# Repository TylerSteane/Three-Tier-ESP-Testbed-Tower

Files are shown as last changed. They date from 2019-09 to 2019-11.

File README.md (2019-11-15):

# Three Tier ESP Testbed Tower

Various research activities require the programming of a large numbers of devices.  This programming can be difficult to co-ordinate and organise, and requires considerable labour time. These issues often mean that testing on real hardware is abandoned or taken only to small scale implementation thus limiting the real-world findings. The method described in the paper 'A Three Tier Rapid Mass Programming Method', adopts a three tiered approach to programming large numbers of devices. Tier 1 is comprised of a single Master Controller which is networked to individual tower modules, these towers form the final 2 tiers with the Local Controller as tier 2 and up-to 15 target devices forming tier 3. The Master Controller co-ordinates and distributes the code for each device to the Local Controller which then programs the target devices. In the domain of networking this allows for:

	* Large networks of varied protocols to be programmed quickly, since towers are programmed in parallel, additional towers don't extend programming times.
	
	* Distributed networks are possible since towers are controlled over Ethernet.
	
	* Low cost as each tower costs around  ~$110 USD.
	
	* Dramatically reduced labour time and defect rates due to human error in setting up devices.

This project implements this method for IoT Networking research with ESP-01 Target devices, including both hardware and software implementations.
Please see the Wiki for instructions on [Configuring a Tower](https://bitbucket.org/tylersteane/three-tier-esp-testbed-tower/wiki/Configuring%20a%20Tower%20Controller)

# Acknowledgement

This work is presented in the research paper : [A Three Tier Rapid Mass Programming Method](https://doi.org/10.1016/j.mex.2019.10.003).
As originally proposed and envisioned by Tyler Steane, with technical work completed by Micheal Trifilo (software) & Christopher Rogash (hardware) as over seen by Tyler Steane & Dr. PJ Radcliffe.

# Citation
Please make use of this project in any of your own work (See [LICENSE](https://github.com/TylerSteane/Three-Tier-ESP-Testbed-Tower/blob/master/LICENSE)), If using any part of this work please cite as:

T. Steane, M. Trifilo, C. Rogash, and P. J. Radcliffe, “A three tier rapid mass programming method,” MethodsX, vol. 6, pp. 2396–2407, Jan. 2019.

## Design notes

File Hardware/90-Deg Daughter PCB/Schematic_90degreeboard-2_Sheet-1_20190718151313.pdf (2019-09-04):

A | A
B | B
C | C
D | D

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
### TITLE:

New Schematic | REV: 1.0
Date: | 2018-09-18 | Sheet: 1/1
EasyEDA V5.7.26 | Drawn By: s3544913

ESP01

U1

GND 1

2TXD 2

GPIO2 3

CHPD 4

VCC 5

RXD 6

RST 7

GPIO0 8

ESP01

U2

GND 1

2TXD 2

GPIO2 3

CHPD 4

VCC 5

RXD 6

RST 7

GPIO0 8

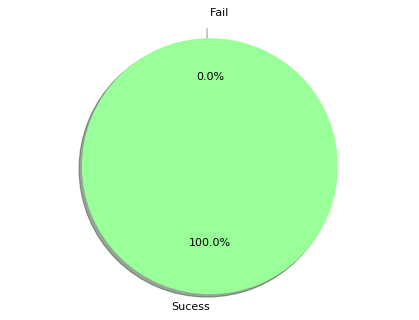
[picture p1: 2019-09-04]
Software/Mgmt_PC/pie.png

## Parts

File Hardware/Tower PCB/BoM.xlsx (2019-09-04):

1 Tower BOM
Part | Quantity | RS Stock Number
Multiplexer – SN74LV4051AN | 8 | 810-0142
Inverter - CD4069UBE | 1 | 527-596
Capacitor - 470µF | 15 | 520-1416
Capacitor – 47nF | 15 | 173-4794
Resistor – 10kΩ | 90 | 165-1031
Headers – 2x20 | 5 | 674-2365
Headers – 2x20 (Right Angle) | 4 | 468-1366
Switches | 15 | Not at RS, source from ali express here (https://www.aliexpress.com/item/20pcs-lot-Electrical-Toggle-Switches-Position-SPDT-1P2T-3-PIN-PCB-Panel-Assembly-Mini-Slide-Switch/32836683151.html)
5V power supply – LRS-100-5 | 1 | 106-5843
Raspberry Pi 3b+ | 1 | 137-3331
Terminal | 1 | 494-8956
Linear Regulator – LM1086CT-3.3/NOPB | 7 | 533-9448
TOTAL

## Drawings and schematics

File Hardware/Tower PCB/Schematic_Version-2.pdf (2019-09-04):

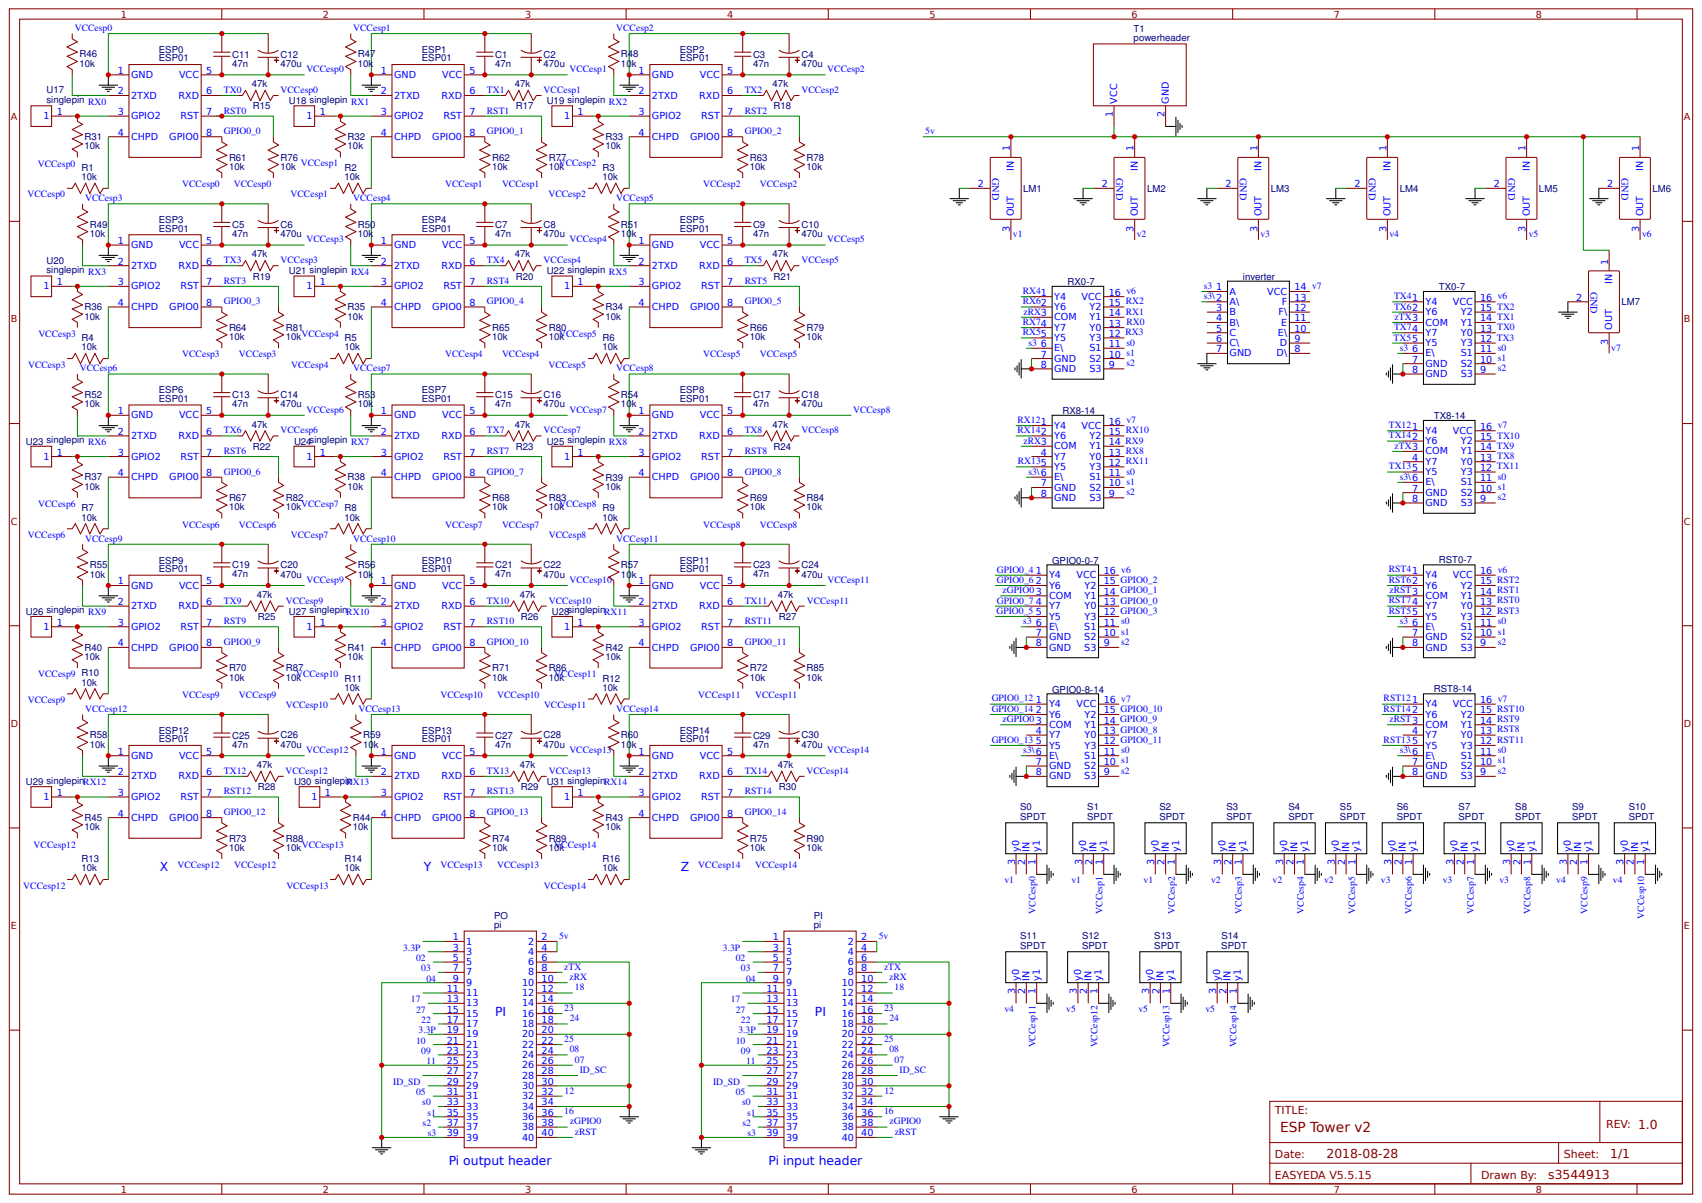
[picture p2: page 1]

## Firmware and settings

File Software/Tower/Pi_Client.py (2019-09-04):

# |**********************************************************************;
# * Project           : ESP Testbed Tower - Client.
# *
# * Program name      : Pi_Client.py
# *
# * Author            : Michael Trifilo
# *
# * Date created      : 16-10-2018
# *
# * Purpose           : Client script to sun on Raspberry Pi on each testbed tower, flash esp devices using serial pins and multiplex selection pins.
# *
# * Dependencies      : RPi.GPIO
# *
# * Usage			  : python Pi_Client.py -mgmt_PC IP address e.g.: 'python Pi_Client.py 192.168.0.100'
# *
# * Revision History  :
# *
# * Date        Author      Ref    Revision
# * 16-10-2018  M Trifilo    1      Initial implementation
# *
# |**********************************************************************;
import platform
import RPi.GPIO as GPIO
import serial
from socket import socket, AF_INET, SOCK_STREAM, SOCK_DGRAM
from threading import Thread
import time, os, sys, select, logging, argparse, subprocess

#GPIO Functions
def GPIO_Setup():
    towerlog.debug('GPIO_Setup Started')
    GPIO.setmode(GPIO.BOARD)
    GPIO.setwarnings(False)
    GPIO.setup(S0,GPIO.OUT)
    GPIO.setup(S1,GPIO.OUT)
    GPIO.setup(S2,GPIO.OUT)
    GPIO.setup(S3,GPIO.OUT)
    GPIO.setup(GPIO0,GPIO.OUT)
    GPIO.setup(RST,GPIO.OUT)
    towerlog.debug('GPIO_Setup Complete')
    
def GPIO_Default():
    towerlog.debug('GPIO_Default Started')
    GPIO.output(S0,0)
    GPIO.output(S1,0)
    GPIO.output(S2,0)
    GPIO.output(S3,0)
    GPIO.output(GPIO0,1)
    GPIO.output(RST,1)
    towerlog.debug('GPIO_Default Complete')
    
def esp_selector(esp):
    towerlog.debug('esp_selector Started')
    if int(esp) == 0:
        esp_binary = '0b0000'
    elif int(esp) == 1:
        esp_binary = '0b0001'
    elif int(esp) == 2:
        esp_binary = '0b0010'
    elif int(esp) == 3:
        esp_binary = '0b0011'
    elif int(esp) == 4:
        esp_binary = '0b0100'
    elif int(esp) == 5:
        esp_binary = '0b0101'
    elif int(esp) == 6:
        esp_binary = '0b0110'
    elif int(esp) == 7:
        esp_binary = '0b0111'
    else:
        esp_binary = bin(int(esp))
    return [esp_binary[5], esp_binary[4], esp_binary[3], esp_binary[2]]
    towerlog.debug('esp_selector Complete')
      
def select_esp(array):
    towerlog.debug('select_esp Started')
    GPIO.output(S0,int(array[0]))
    GPIO.output(S1,int(array[1]))
    GPIO.output(S2,int(array[2]))
    GPIO.output(S3,int(array[3]))
    towerlog.debug('select_esp Complete')

def reset_esp(esp, bootmode):
    towerlog.debug('reset_esp Started')
    #Select ESP
    select_esp(esp_selector(esp))
    #Set GPIO Bootmode
    GPIO.output(GPIO0,bootmode)
    #Set RST LOW
    GPIO.output(RST,0)
    time.sleep(1)
    #Set RST HIGH
    GPIO.output(RST,1)
    time.sleep(1)
    towerlog.debug('reset_esp Complete')
    
def flash_esp(esp, port, location, file):
    towerlog.info('Flashing ESP: ' + str(esp))
    #Reset ESP to Program Mode
    reset_esp(esp,0)
    #Build command to call esptool.py
    command = []
    command.append(esptool_path)
    command.append('--port')
    command.append(port)
    command.append('write_flash')
    command.append(location)
    command.append(file)
    #Create subprocess
    flash_shell = subprocess.Popen(command,stdout=subprocess.PIPE)
    while True: #Check output, log and send to server
        cmd_output = flash_shell.stdout.readline().rstrip()
        if cmd_output == '' and flash_shell.poll() is not None:
            break
        else:
            towerlog.info(cmd_output)
            client_socket.send(cmd_output)
    #Reset ESP to Boot Mode
    reset_esp(esp,1)
            
def receive():
    global connected
    try:
        msg = client_socket.recv(BUFSIZ).decode("utf8")
        if msg == 'Name?': # Name Request
            client_socket.send(my_name) # Name Response
        elif msg == 'FILES!': # File Transfer Request
            size = client_socket.recv(16) # Filename Size
            if not size:
                towerlog.info('File Transfer Error!')
            size = int(size, 2)
            filename = client_socket.recv(size) # Filename
            filesize = client_socket.recv(32) # File Size
            filesize = int(filesize, 2)
            file_to_write = open(filename, 'wb')
            chunksize = 4096
            # Recieve File data
            while filesize > 0:
                if filesize < chunksize:
                    chunksize = filesize
                data = client_socket.recv(chunksize)
                file_to_write.write(data)
                filesize -= len(data)
            file_to_write.close() # Write Data to new file
            client_socket.send('Done') # File Transfered
        elif msg == 'Flash':
            size = client_socket.recv(32) # Command Size
            if not size:
                towerlog.info('Flash Command Transfer Error!')
            size = int(size, 2)
            command = client_socket.recv(size) # Command
            command = command.split(' ')
            flash_esp(command[2], serial_port, flash_location, command[3])
            time.sleep(2)
            client_socket.send('Done')
    except: # Connection Error
        connected = False
        client_socket.close()
        time.sleep(2)

def send(message):  #Send Message
    client_socket.send(bytes(message, "utf8"))
    if message == "{quit}":
        client_socket.close()

##Logging
# create logger with 'ESP Logger'
towerlog = logging.getLogger('Tower_Logger')
towerlog.setLevel(logging.DEBUG)
# create file handler which logs everything
fh = logging.FileHandler('Tower_Log.log')
fh.setLevel(logging.DEBUG)
# create console handler with a higher log level
ch = logging.StreamHandler()
ch.setLevel(logging.INFO)
# create formatter and add it to the handlers
formatter = logging.Formatter('%(asctime)s - %(levelname)s - %(message)s')
fh.setFormatter(formatter)
ch.setFormatter(formatter)
# add the handlers to the logger
towerlog.addHandler(fh)
towerlog.addHandler(ch)

## Variables

#Pin Numbers
my_name = platform.node()
S0 = 31
S1 = 33
S2 = 35
S3 = 37
GPIO0 = 38
RST = 40

#Env Variables
esptool_path = '/home/pi/esptool/esptool.py'
serial_port = '/dev/serial0'
flash_location = '0x0'

#Parse Arguments
parser = argparse.ArgumentParser()
parser.add_argument("host", help="IP of the Mgmt PC")
args = parser.parse_args()

#Socket Variables
connected = False
HOST = args.host
PORT = 5000
BUFSIZ = 1024
ADDR = (HOST, PORT)

#Setup GPIO
GPIO_Setup()

#Default GPIO Values
GPIO_Default()

# Main Connection Loop
while True:
    while not connected: # Remake socket and try to connect
        try:
            client_socket = socket(AF_INET, SOCK_STREAM)
            towerlog.info('Attemting to connect to server')
            client_socket.connect(ADDR)
            connected = True
            towerlog.info('Connected to host!')
        except:
            towerlog.info('Connection Timeout')
            connected = False
            time.sleep(2)
    while connected: # When connected call recieve()
        receive()
